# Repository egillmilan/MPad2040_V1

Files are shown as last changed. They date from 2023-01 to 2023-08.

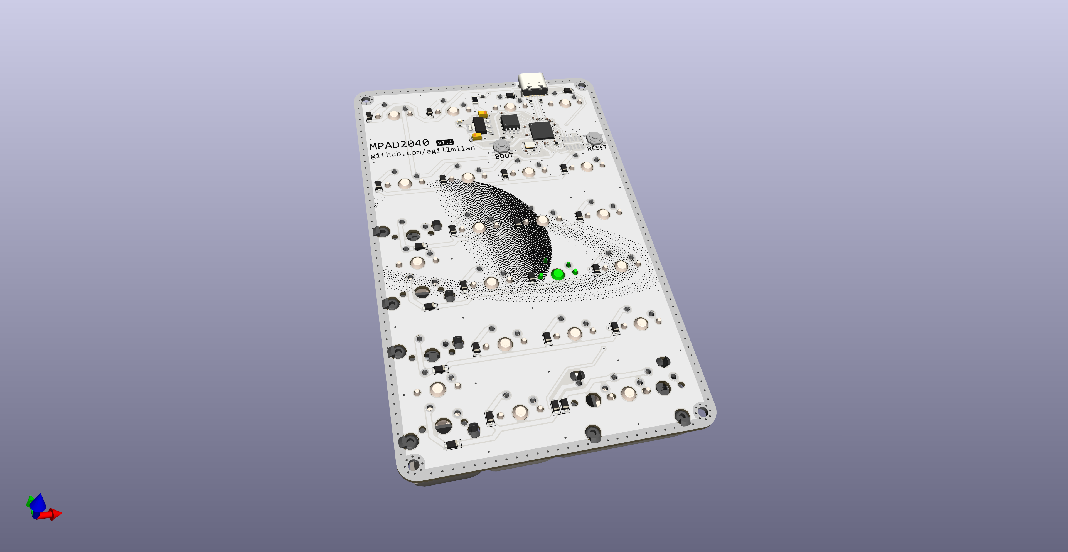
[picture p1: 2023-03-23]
Images/MPad2040_V1_1.png

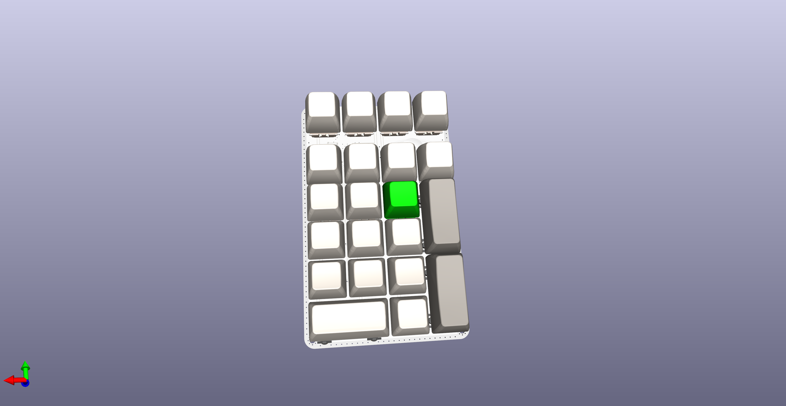
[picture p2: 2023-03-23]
Images/MPad2040_V1_3.png

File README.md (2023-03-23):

# MPad2040_V1
Numpad based on the RP2040 microcontroller. Uses USB-C and has a macro-row at the top. [Schematic can be found here.](https://github.com/egillmilan/MPad2040_V1/files/11053267/MPad2040_V1.pdf)

MPad2040_V1_1
MPad2040_V1_2
MPad2040_V1_3

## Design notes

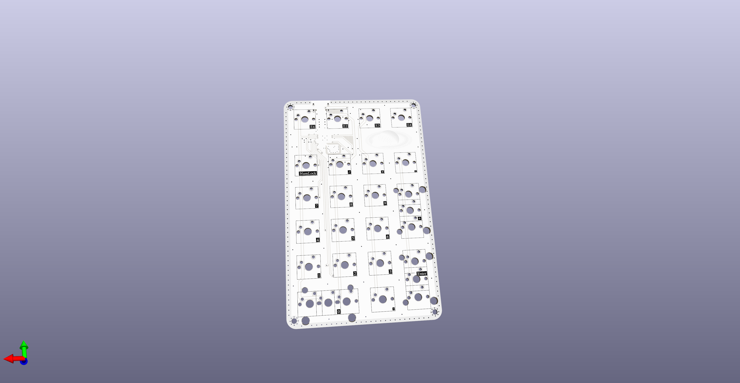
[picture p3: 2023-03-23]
Images/MPad2040_V1_2.png

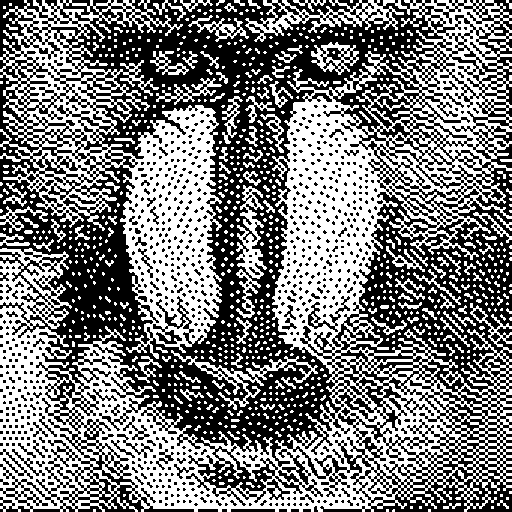
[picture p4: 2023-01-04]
Silkscreen_art/output_images/baboonFloydSteinbergDots.bmp

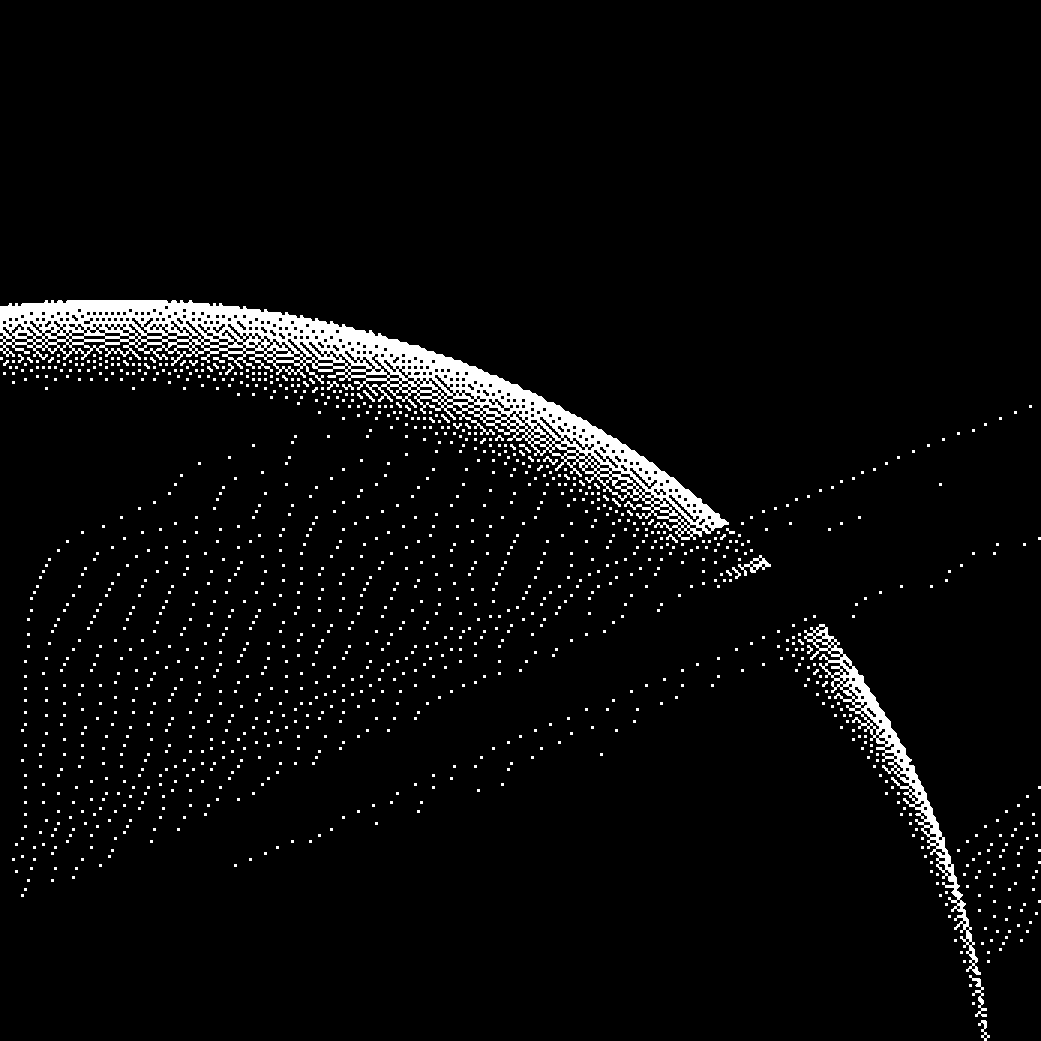
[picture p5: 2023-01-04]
Silkscreen_art/saturn/edited/saturn13_e.bmp

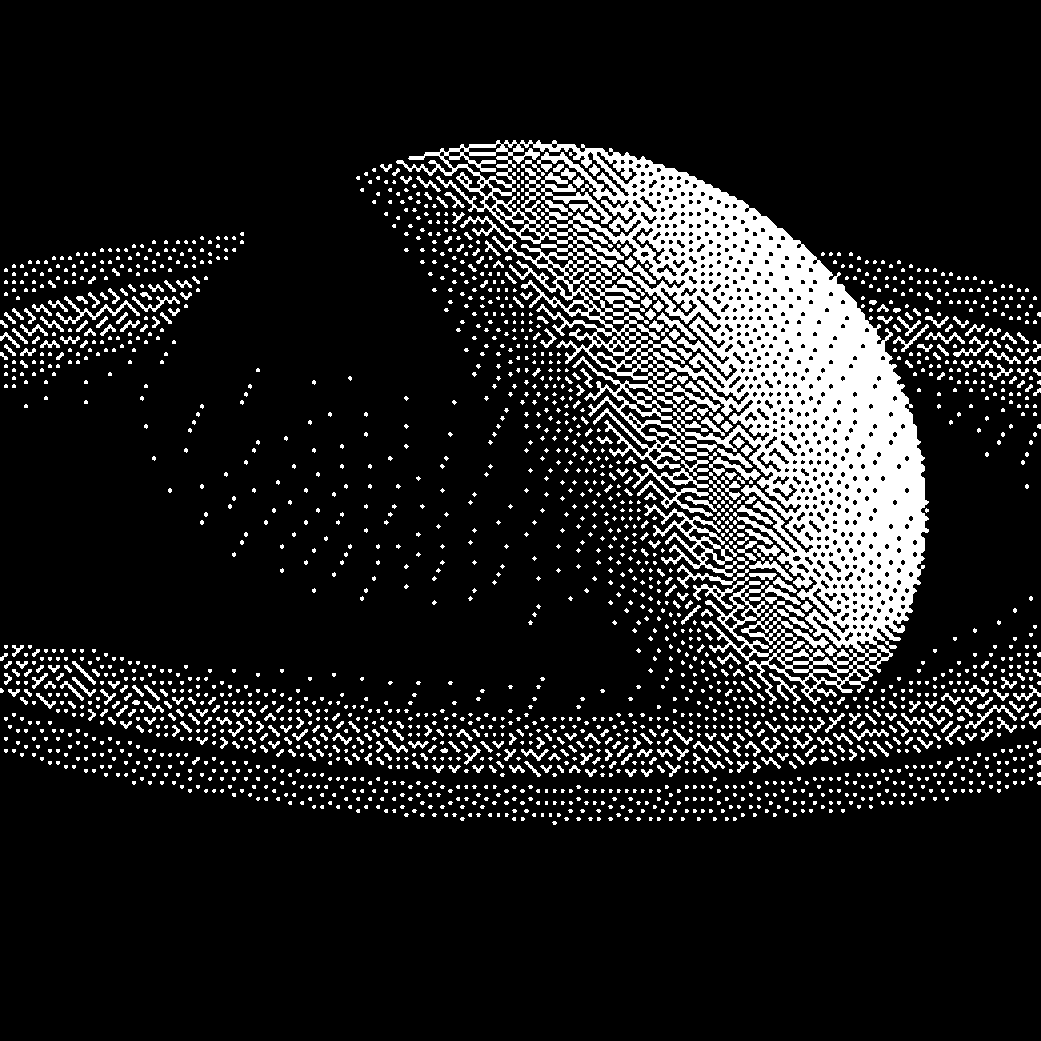
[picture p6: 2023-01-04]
Silkscreen_art/saturn/edited/saturn7_e.bmp

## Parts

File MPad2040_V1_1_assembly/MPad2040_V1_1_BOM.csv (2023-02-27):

Comment | Designator | Footprint | LCSC Part Number
100nF | C1, C5, C6, C7, C8, C13, C14, C15, C16, C18 | 402 | C1525
22uF | C2, C3 | CASE-A-3216 | C97062
1uF | C4, C11 | 402 | C52923
30pF | C9, C10 | 402 | C1570
Green LED | D1 | 603 | C72043
SM4007 | D2, D3, D4, D5, D6, D7, D8, D9, D10, D11, D12, D13, D14, D15, D16, D17, D18, D19, D20, D21, D22, D23, D24, D25 | SOD-123FL | C64898
500mA | F1 | 1206 | C206992
220R@100MHz | FB1 | 603 | C80165
USB_C_Receptacle | J2 | SMD | C2760486
10k | R1 | 603 | C25804
5k1 | R2, R3 | 603 | C23186
1k | R4, R7, R8 | 402 | C11702
27R | R5, R6 | 402 | C226392
TS-1187A-B-A-B | SW28,SW29 | SMD | C318884
RP2040 | U1 | LQFN-56(7x7) | C2040
AMS1117-3.3 | U2 | SOT-223-3 | C6186
W25Q16JVSSIQ | U3 | SOIC-8-208mil | C82317
12MHz | Y1 | SMD3225-4P | C9002

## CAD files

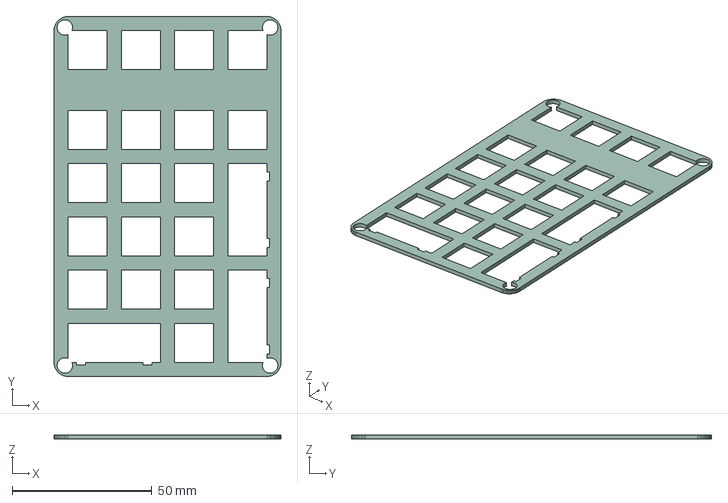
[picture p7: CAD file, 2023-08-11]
3D_files/MPad2040_Plate.step
81.3 x 128.9 x 1.60 mm

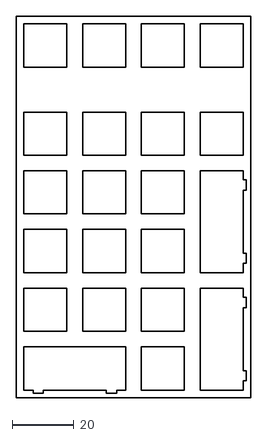
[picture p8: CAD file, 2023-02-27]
MPad2040_Plate/MPad2040_Plate.dxf
76.2 x 123.8

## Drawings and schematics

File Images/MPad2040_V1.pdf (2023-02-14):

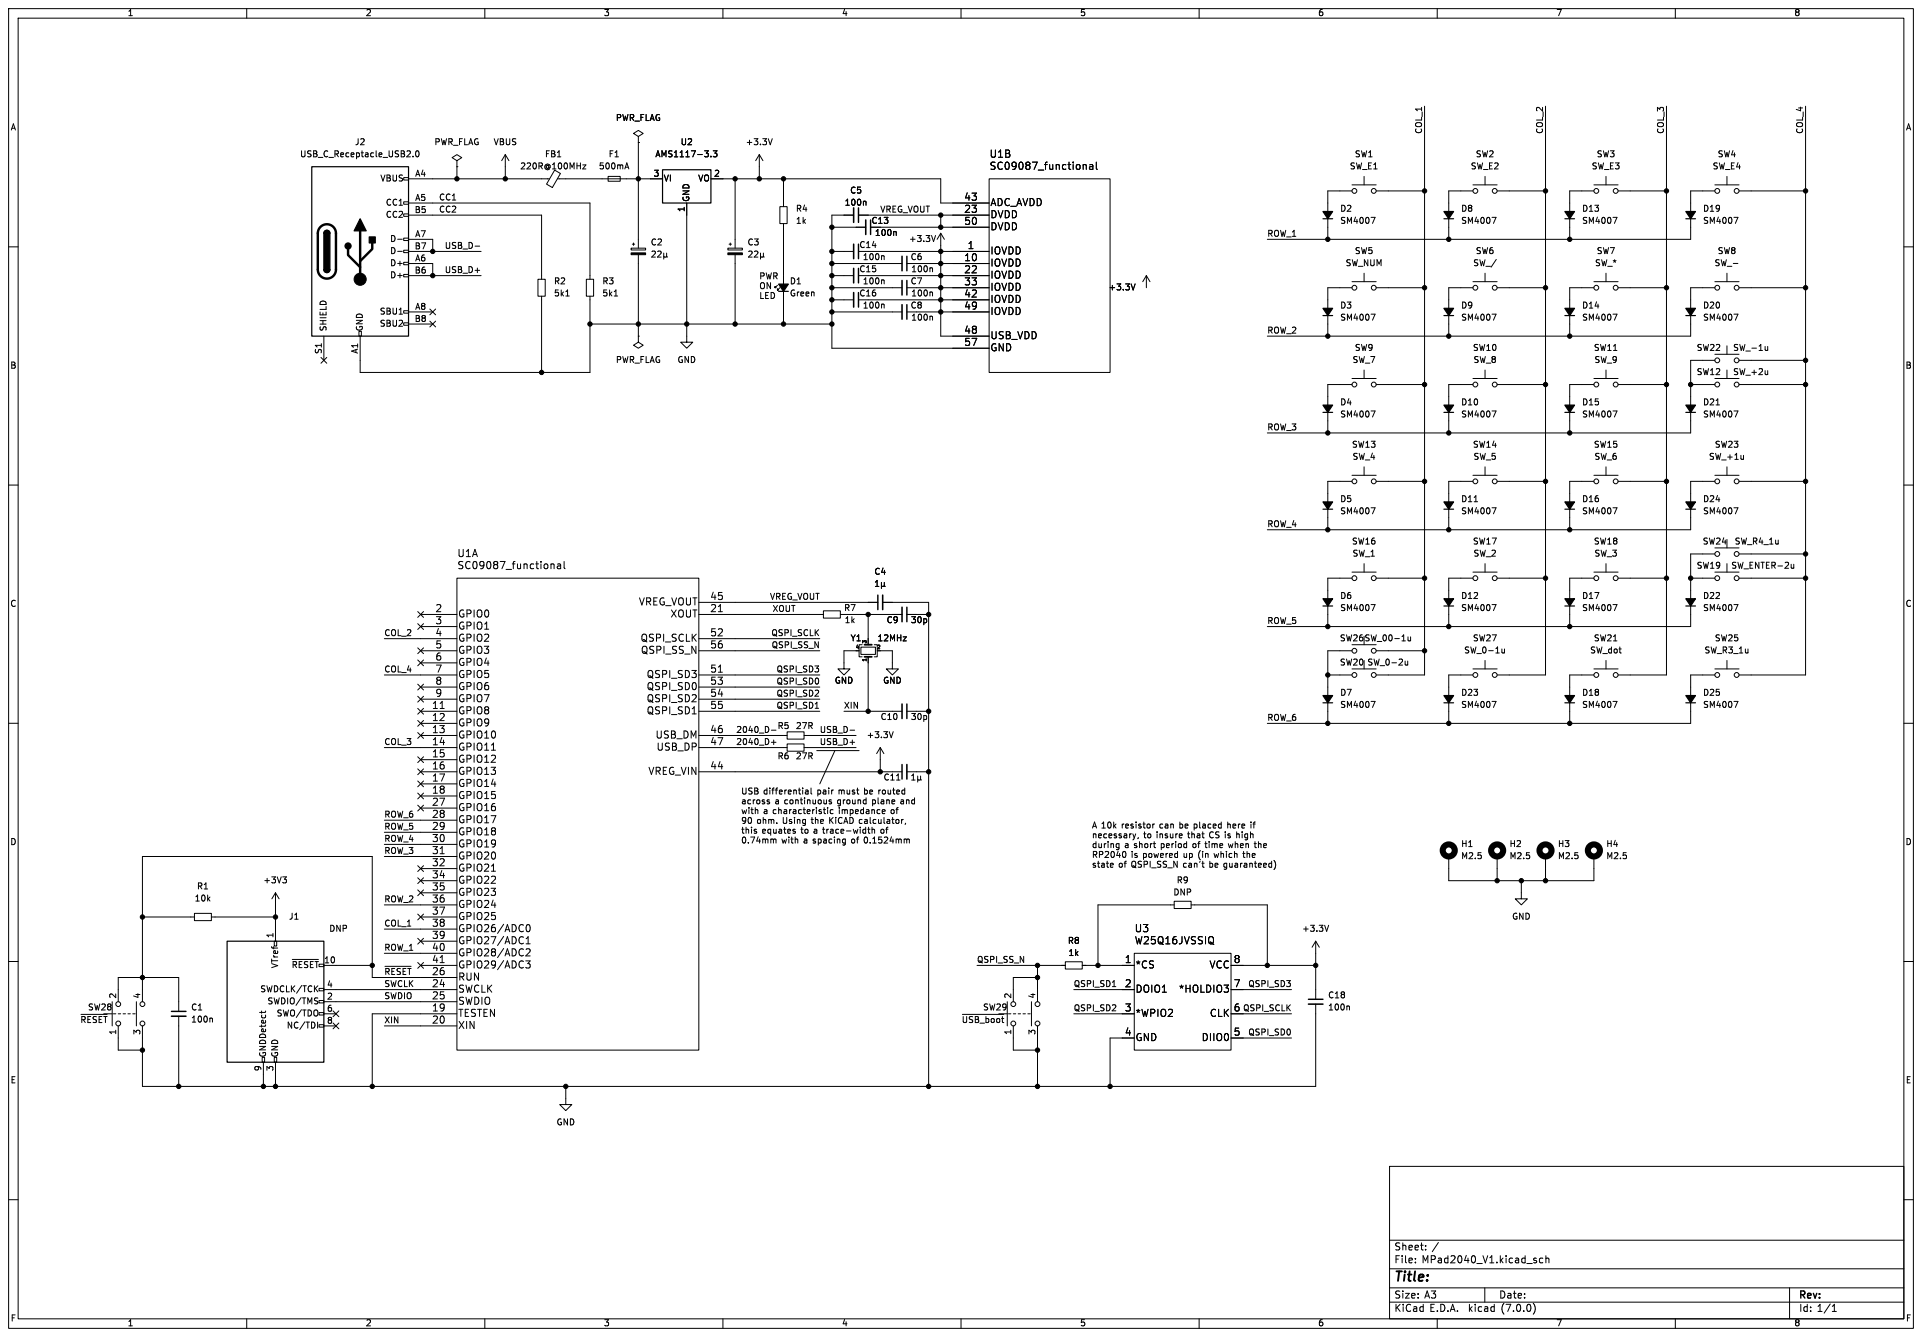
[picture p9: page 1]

state of QSPI_SS_N can't be guaranteed) C4

A 10k resistor can be placed here if necessary, to insure that CS is high

during a short period of time when the RP2040 is powered up (in which the

3 SWDCLK/TCK 4 SWO/TDO 6 NC/TDI 8 GNDDetect 9

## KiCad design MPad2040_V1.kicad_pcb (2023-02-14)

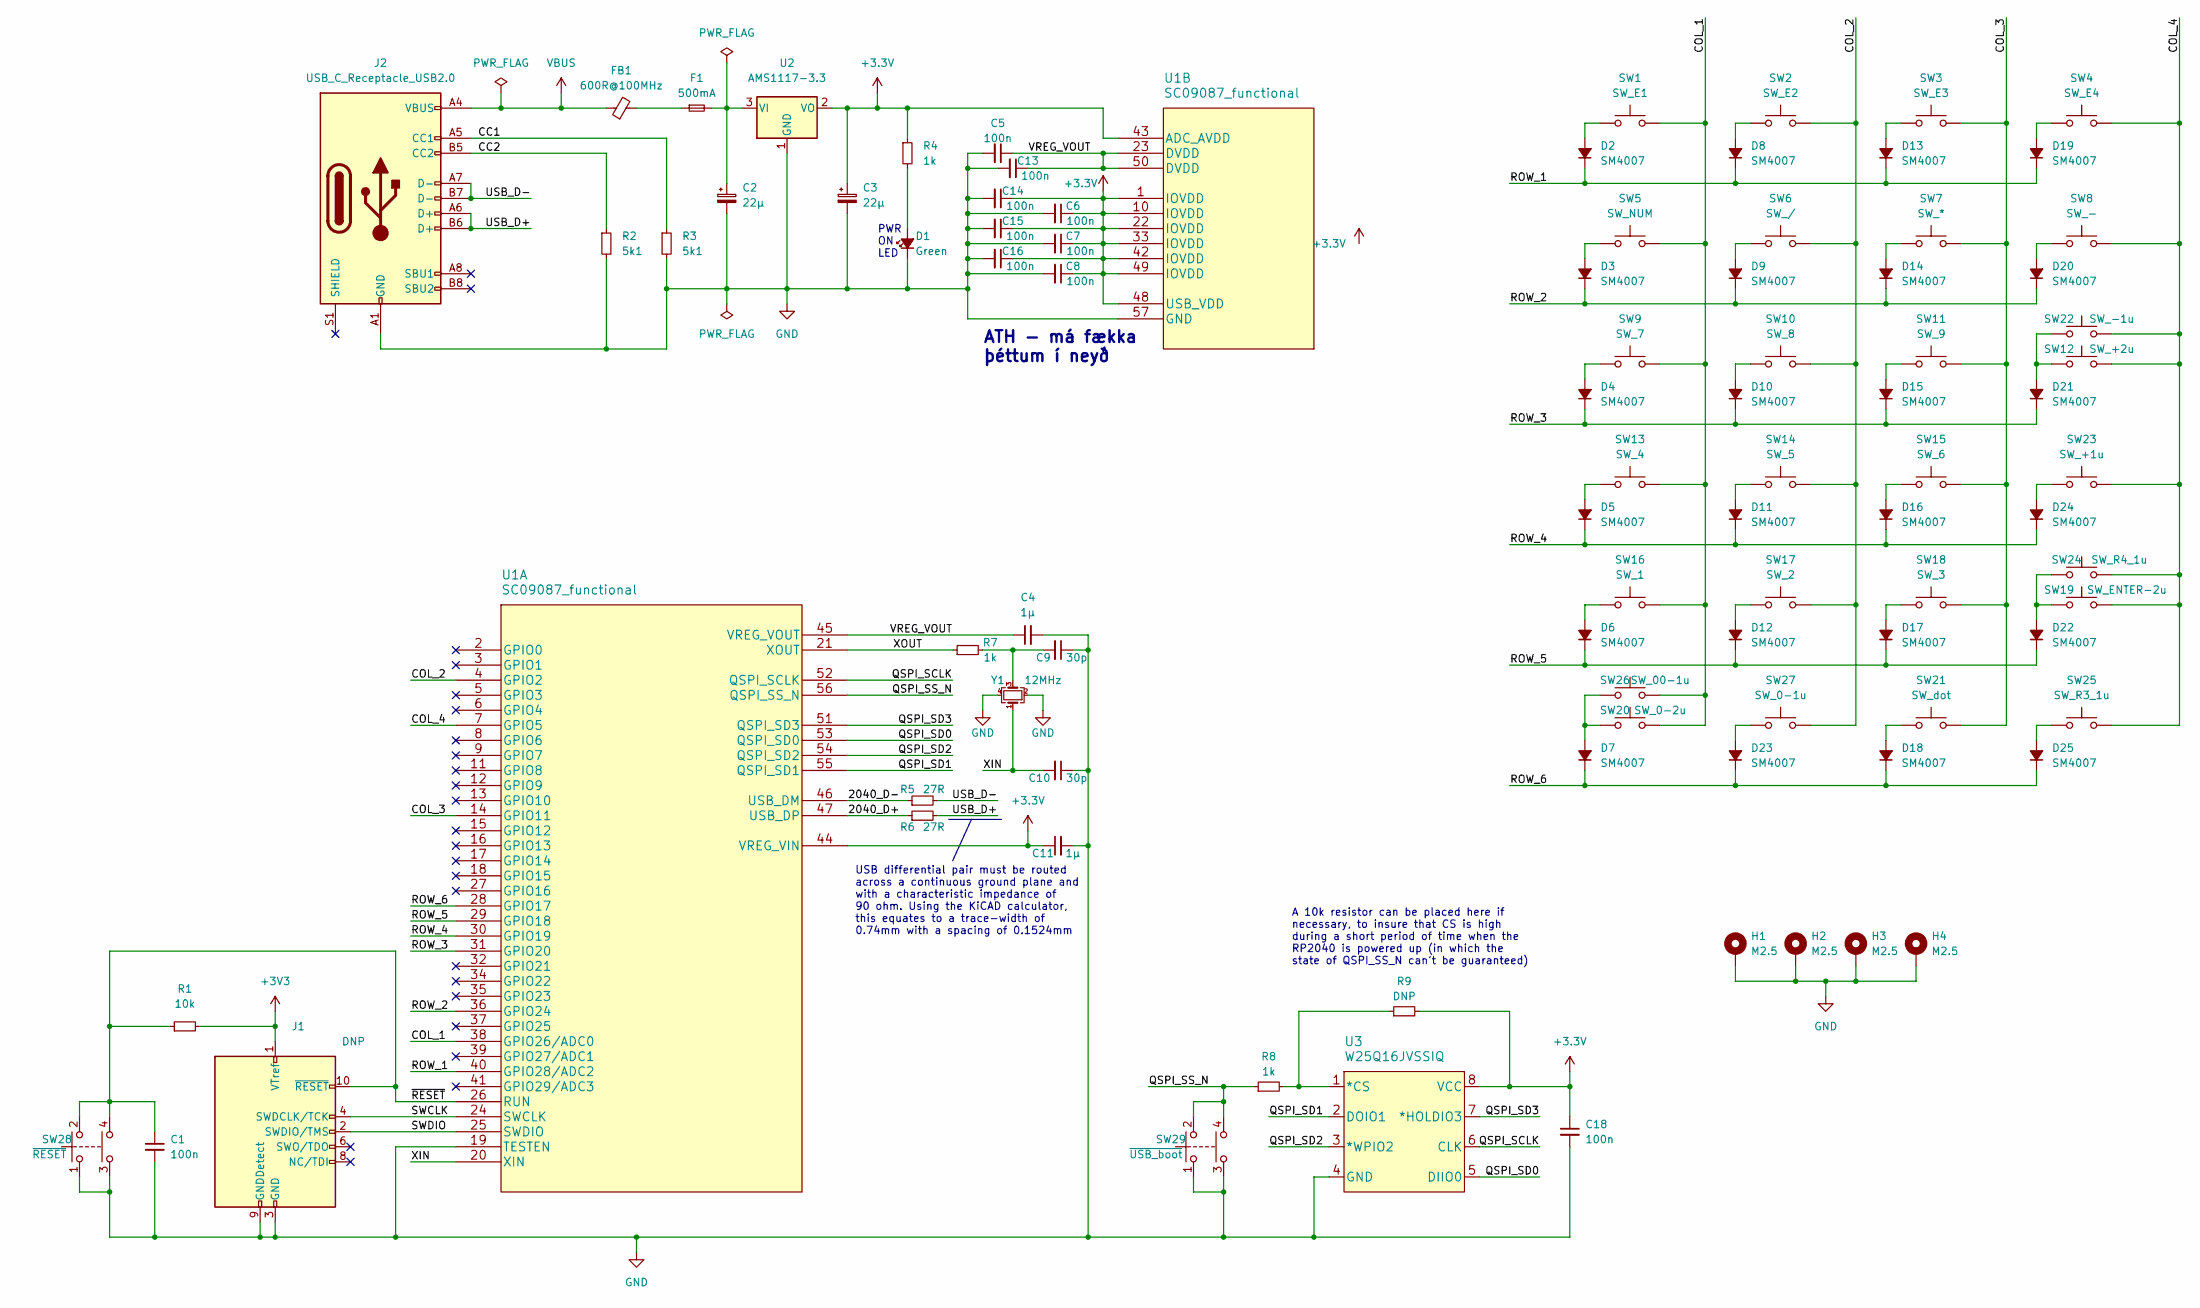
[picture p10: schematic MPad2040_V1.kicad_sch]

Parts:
C1, C5, C6, C7, C8, C13, C14, C15, C16, C18: 100n; C_0402_1005Metric
C2, C3: 22µ; CP_EIA-3216-18_Kemet-A
C4, C11: 1µ; C_0402_1005Metric
C9, C10: 30p; C_0402_1005Metric
D1: Green; LED_0603_1608Metric
D2, D3, D4, D5, D6, D7, D8, D9, D10, D11, D12, D13, D14, D15, D16, D17, D18, D19, D20, D21, D22, D23, D24, D25: SM4007; D_SOD-123F
F1: 500mA; Fuse_1206_3216Metric
FB1: 600R@100MHz; L_0603_1608Metric
H1, H2, H3, H4: M2.5; MountingHole_2.7mm_M2.5_Pad_Via
J1: DNP; PinSocket_2x05_P1.27mm_Vertical_SMD
J2: USB_C_Receptacle_USB2.0; USB_C_Receptacle_GCT_USB4085
R1: 10k; R_0603_1608Metric
R2, R3: 5k1; R_0603_1608Metric
R4, R7, R8: 1k; R_0603_1608Metric
R5, R6: 27R; R_0603_1608Metric
R9: DNP; R_0603_1608Metric
SW1: SW_E1; SW_Cherry_MX_1.00u_R1
SW2: SW_E2; SW_Cherry_MX_1.00u_R1
SW3: SW_E3; SW_Cherry_MX_1.00u_R1
SW4: SW_E4; SW_Cherry_MX_1.00u_R1
SW5: SW_NUM; SW_Cherry_MX_1.00u_R1
SW6: SW_/; SW_Cherry_MX_1.00u_R1
SW7: SW_*; SW_Cherry_MX_1.00u_R1
SW8: SW_-; SW_Cherry_MX_1.00u_R1
SW9: SW_7; SW_Cherry_MX_1.00u_R3
SW10: SW_8; SW_Cherry_MX_1.00u_R3
SW11: SW_9; SW_Cherry_MX_1.00u_R3
SW12: SW_+2u; SW_Cherry_MX_2.00u_Vertical_PCB
SW13: SW_4; SW_Cherry_MX_1.00u_R3
SW14: SW_5; SW_Cherry_MX_1.00u_R3
SW15: SW_6; SW_Cherry_MX_1.00u_R3
SW16: SW_1; SW_Cherry_MX_1.00u_R4
SW17: SW_2; SW_Cherry_MX_1.00u_R4
SW18: SW_3; SW_Cherry_MX_1.00u_R4
SW19: SW_ENTER-2u; SW_Cherry_MX_2.00u_Vertical_PCB
SW20: SW_0-2u; SW_Cherry_MX_2.00u_PCB
SW21: SW_dot; SW_Cherry_MX_1.00u_R3
SW22: SW_-1u; SW_Cherry_MX_1.00u_R2
SW23: SW_+1u; SW_Cherry_MX_1.00u_R3
SW24: SW_R4_1u; SW_Cherry_MX_1.00u_R4
SW25: SW_R3_1u; SW_Cherry_MX_1.00u_R3
SW26: SW_00-1u; SW_Cherry_MX_1.00u_R3
SW27: SW_0-1u; SW_Cherry_MX_1.00u_R3
SW28: ~{RESET}; SW_TS-1187A-B-A-B
SW29: ~{USB_boot}; SW_TS-1187A-B-A-B
U1: SC09087_functional; SC09087
U2: AMS1117-3.3; SOT-223-3_TabPin2
U3: W25Q16JVSSIQ
Y1: 12MHz; Crystal_SMD_3225-4Pin_3.2x2.5mm

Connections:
/2040_D+: R6.1, U1.47 (USB_DP)
/2040_D-: R5.1, U1.46 (USB_DM)
/CC1: J2.A5 (CC1), R3.1
/CC2: J2.B5 (CC2), R2.1
/COL_1: SW1.2, SW5.2, SW9.2, SW13.2, SW16.2, SW20.2, SW26.2, U1.38 (GPIO26/ADC0)
/COL_2: SW2.2, SW6.2, SW10.2, SW14.2, SW17.2, SW27.2, U1.4 (GPIO2)
/COL_3: SW3.2, SW7.2, SW11.2, SW15.2, SW18.2, SW21.2, U1.14 (GPIO11)
/COL_4: SW4.2, SW8.2, SW12.2, SW19.2, SW22.2, SW23.2, SW24.2, SW25.2, U1.7 (GPIO5)
/QSPI_SCLK: U1.52 (QSPI_SCLK), U3.6 (CLK)
/QSPI_SD0: U1.53 (QSPI_SD0), U3.5 (DIIO0)
/QSPI_SD1: U1.55 (QSPI_SD1), U3.2 (DOIO1)
/QSPI_SD2: U1.54 (QSPI_SD2), U3.3 (*WPIO2)
/QSPI_SD3: U1.51 (QSPI_SD3), U3.7 (*HOLDIO3)
/QSPI_SS_N: R8.1, SW29.2, SW29.4, U1.56 (QSPI_SS_N)
/ROW_1: D2.1 (K), D8.1 (K), D13.1 (K), D19.1 (K), U1.40 (GPIO28/ADC2)
/ROW_2: D3.1 (K), D9.1 (K), D14.1 (K), D20.1 (K), U1.36 (GPIO24)
/ROW_3: D4.1 (K), D10.1 (K), D15.1 (K), D21.1 (K), U1.31 (GPIO20)
/ROW_4: D5.1 (K), D11.1 (K), D16.1 (K), D24.1 (K), U1.30 (GPIO19)
/ROW_5: D6.1 (K), D12.1 (K), D17.1 (K), D22.1 (K), U1.29 (GPIO18)
/ROW_6: D7.1 (K), D18.1 (K), D23.1 (K), D25.1 (K), U1.28 (GPIO17)
/SWCLK: J1.4 (SWDCLK/TCK), U1.24 (SWCLK)
/SWDIO: J1.2 (SWDIO/TMS), U1.25 (SWDIO)
/USB_D+: J2.A6 (D+), J2.B6 (D+), R6.2
/USB_D-: J2.A7 (D-), J2.B7 (D-), R5.2
/VREG_VOUT: C4.1, C5.1, C13.1, U1.23 (DVDD), U1.45 (VREG_VOUT), U1.50 (DVDD)
/XIN: C10.2, U1.20 (XIN), Y1.1
/XOUT: R7.1, U1.21 (XOUT)
/~RESET: C1.1, J1.10 (~RESET), R1.1, SW28.2, SW28.4, U1.26 (RUN)
GND: C1.2, C2.2, C3.2, C4.2, C5.2, C6.2, C7.2, C8.2, C9.1, C10.1, C11.2, C13.2, C14.2, C15.2, C16.2, C18.2, D1.1 (K), H1.1, H2.1, H3.1, H4.1, J1.3 (GND), J1.5 (GND), J1.9 (GNDDetect), J2.A1 (GND), J2.A12 (GND), J2.B1 (GND), J2.B12 (GND), R2.2, R3.2, SW28.1, SW28.3, SW29.1, SW29.3, U1.19 (TESTEN), U1.57 (GND), U2.1 (GND), U3.4 (GND), Y1.2, Y1.4
unnamed: C2.1, F1.2, U2.3 (VI)
unnamed: C9.2, R7.2, Y1.3
unnamed: D1.2 (A), R4.2
unnamed: D2.2 (A), SW1.1
unnamed: D3.2 (A), SW5.1
unnamed: D4.2 (A), SW9.1
unnamed: D5.2 (A), SW13.1
unnamed: D6.2 (A), SW16.1
unnamed: D7.2 (A), SW20.1, SW26.1
unnamed: D8.2 (A), SW2.1
unnamed: D9.2 (A), SW6.1
unnamed: D10.2 (A), SW10.1
unnamed: D11.2 (A), SW14.1
unnamed: D12.2 (A), SW17.1
unnamed: D13.2 (A), SW3.1
unnamed: D14.2 (A), SW7.1
unnamed: D15.2 (A), SW11.1
unnamed: D16.2 (A), SW15.1
unnamed: D17.2 (A), SW18.1
unnamed: D18.2 (A), SW21.1
unnamed: D19.2 (A), SW4.1
unnamed: D20.2 (A), SW8.1
unnamed: D21.2 (A), SW12.1, SW22.1
unnamed: D22.2 (A), SW19.1, SW24.1
unnamed: D23.2 (A), SW27.1
unnamed: D24.2 (A), SW23.1
unnamed: D25.2 (A), SW25.1
unnamed: F1.1, FB1.2
unnamed: R8.2, R9.1, U3.1 (*CS)
VBUS: FB1.1, J2.A4 (VBUS), J2.A9 (VBUS), J2.B4 (VBUS), J2.B9 (VBUS)

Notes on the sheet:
PWR ON LED
ATH - má fækka þéttum í neyð
A 10k resistor can be placed here if necessary, to insure that CS is high during a short period of time when the RP2040 is powered up (in which the state of QSPI_SS_N can't be guaranteed)
USB differential pair must be routed across a continuous ground plane and with a characteristic impedance of 90 ohm. Using the KiCAD calculator, this equates to a trace-width of 0.74mm with a spacing of 0.1524mm

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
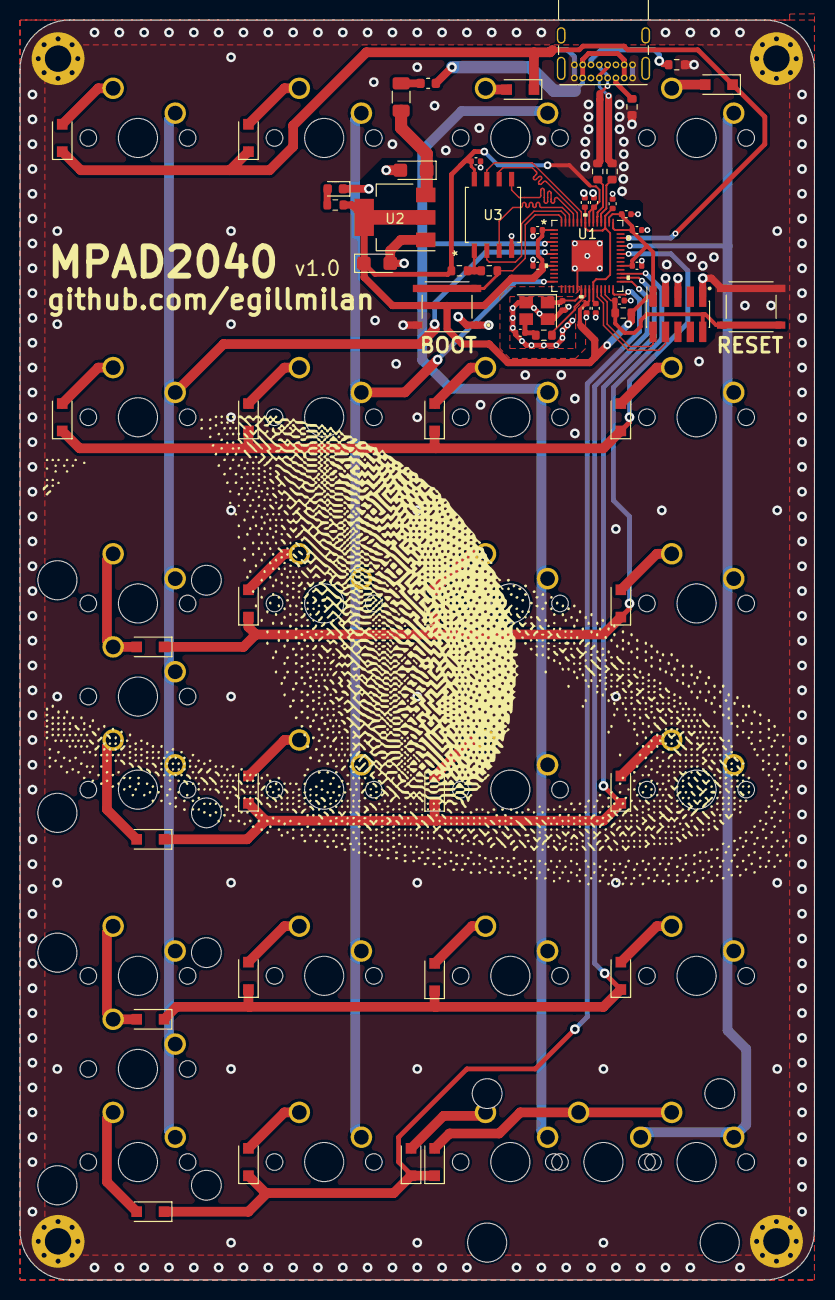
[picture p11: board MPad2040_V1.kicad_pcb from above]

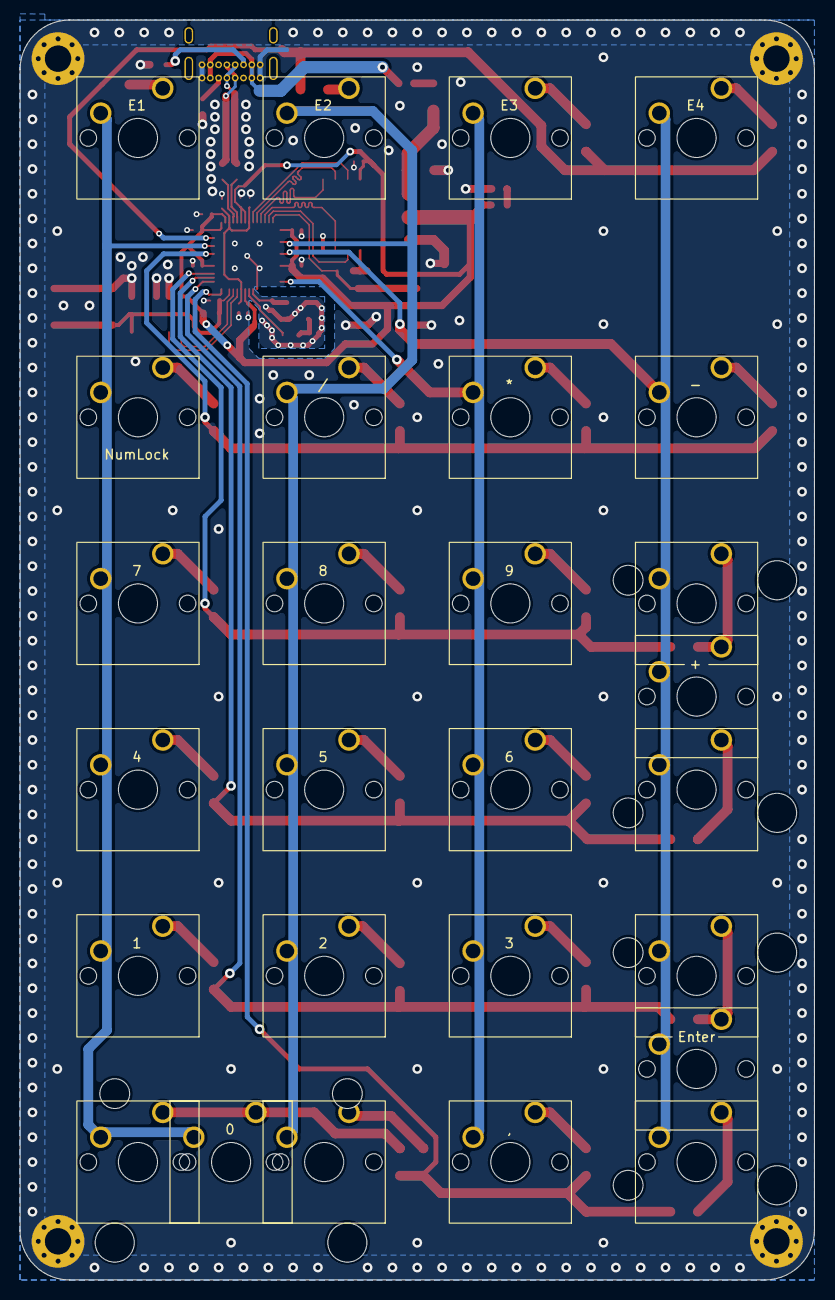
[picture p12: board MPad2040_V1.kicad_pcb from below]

Board: 2 copper layers, 81.3 x 128.9 mm, 91 parts (31 on the bottom side), 60 nets.

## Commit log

2023-02-14 Version 1.1 finalized
    [MPad2040_V1-B_Cu.gbl, MPad2040_V1-B_Mask.gbs, MPad2040_V1-B_Paste.gbp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]
2023-02-18 Fixes for V1.1
    [MPad2040_V1-B_Cu.gbl, MPad2040_V1-B_Mask.gbs, MPad2040_V1-B_Paste.gbp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]
2023-02-24 Font changes on silkscreen
2023-02-27 Added plate
    [MPad2040_Plate.dxf, MPad2040_Plate.kicad_pcb, MPad2040_Plate.kicad_sch]
2023-02-27 Ready for production
    [MPad2040_Plate.kicad_pcb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]
2023-08-11 added 3D files
    [MPad2040_Plate.step]
